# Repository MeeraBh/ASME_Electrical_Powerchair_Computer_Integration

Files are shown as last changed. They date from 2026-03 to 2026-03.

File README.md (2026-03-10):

# ASME Electrical Powerchair Computer Integration
This is repo contains the schematic, pcb, and gerber files from Kicad for a custom ortholinear split keyboard PCB as well as all files needed to order the pcb on JLCPCB.

This project was made for ASME - Product Development and will be shown at Engineering Open House.  

It is intended to be used for a powerchair in which the PCB contains the peripherals for the computer minus the monitor itself in which the mainboard of the computer is connected to the powerchair.  These peripherals are the keyboard itself, 2 OLED screens (Nice!Views), and 2 joysticks.  There are also a total of 3 microcontrollers (Nice!Nanos) that can connect to each other through bluetooth and communicate.  The keyboard can also be used as split design or merged together as a full keyboard due to the connections in the center.

# Keyboard
PCB
Screenshot 2026-03-09 at 12 35 01 AM
3D View Front
Screenshot 2026-03-09 at 12 34 24 AM
3D View Back
Screenshot 2026-03-09 at 12 36 32 AM
Schematic

Screenshot 2026-03-09 at 12 34 24 AM (2)

Gerber, BOM, and CTL (.pos) files in repo that are compatible with JLCPCB printing.

Details on full project: https://erinpc.vercel.app

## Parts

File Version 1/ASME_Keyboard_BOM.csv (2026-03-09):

Id | Designator | Footprint | Quantity | Designation | Supplier and ref
1 | SW28,SW36,SW40,SW15,SW35,SW26,SW31,SW17,SW24,SW18,SW38,SW1,SW21,SW16,SW5,SW33,SW22,SW41,SW34,SW4,SW32,SW12,SW42,SW14,SW23,SW37,SW30,SW3,SW9,SW10,SW7,SW27,SW20,SW6,SW19,SW25,SW11,SW13,SW2,SW8,SW29,SW39 | Kailh_socket_MX | 42 | SW_Push
2 | J16,J17,J6,J13,J15,J14 | MF_Connectors-POGO_PIN_70-9150 | 6 | Conn_01x01_Socket
3 | J1,J11,J10,J12,J9,J8 | MF_Connectors-POGO_PIN_70-9150 | 6 | Conn_01x01_Pin
4 | J22,J7,J20,J21,J19,J18 | PinHeader_1x05_P2.54mm_Vertical | 6 | Conn_01x05_Pin
5 | U1,U2,U3 | nice_nano | 3 | nice_nano
6 | J4,J2 | nice_view | 2 | Conn_01x05_Pin
7 | J3,J5 | Joycon_edited_5pin | 2 | Conn_01x05_Pin
8 | JP1 | SolderJumper-2_P1.3mm_Open_Pad1.0x1.5mm | 1 | Jumper_2_Bridged
9 | D11,D32,D40,D28,D5,D38,D25,D12,D8,D37,D29,D9,D21,D6,D14,D7,D42,D39,D23,D19,D15,D13,D36,D17,D3,D10,D30,D22,D27,D31,D35,D4,D18,D26,D16,D20,D1,D24,D34,D41,D33,D2 | D_1206_3216Metric | 42 | D

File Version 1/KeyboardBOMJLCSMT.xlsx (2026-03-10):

Comment | Designator | Footprint | JLCPCB Part #（optional）
SW_Push | SW28,SW36,SW40,SW15,SW35,SW26,SW31,SW17,SW24,SW18,SW38,SW1,SW21,SW16,SW5,SW33,SW22,SW41,SW34,SW4,SW32,SW12,SW42,SW14,SW23,SW37,SW30,SW3,SW9,SW10,SW7,SW27,SW20,SW6,SW19,SW25,SW11,SW13,SW2,SW8,SW29,SW39 | Kailh_socket_MX | CPG135001S30
Conn_01x01_Socket | J16,J17,J6,J13,J15,J14 | MF_Connectors-POGO_PIN_70-9150
Conn_01x01_Pin | J1,J11,J10,J12,J9,J8 | MF_Connectors-POGO_PIN_70-9150
Conn_01x05_Pin | J22,J7,J20,J21,J19,J18 | PinHeader_1x05_P2.54mm_Vertical
nice_nano | U1,U2,U3 | nice_nano
Conn_01x05_Pin | J4,J2 | nice_view
Conn_01x05_Pin | J3,J5 | Joycon_edited_5pin | Molex 503480-0500
D | D11,D32,D40,D28,D5,D38,D25,D12,D8,D37,D29,D9,D21,D6,D14,D7,D42,D39,D23,D19,D15,D13,D36,D17,D3,D10,D30,D22,D27,D31,D35,D4,D18,D26,D16,D20,D1,D24,D34,D41,D33,D2 | D_1206_3216Metric | 1N4148W

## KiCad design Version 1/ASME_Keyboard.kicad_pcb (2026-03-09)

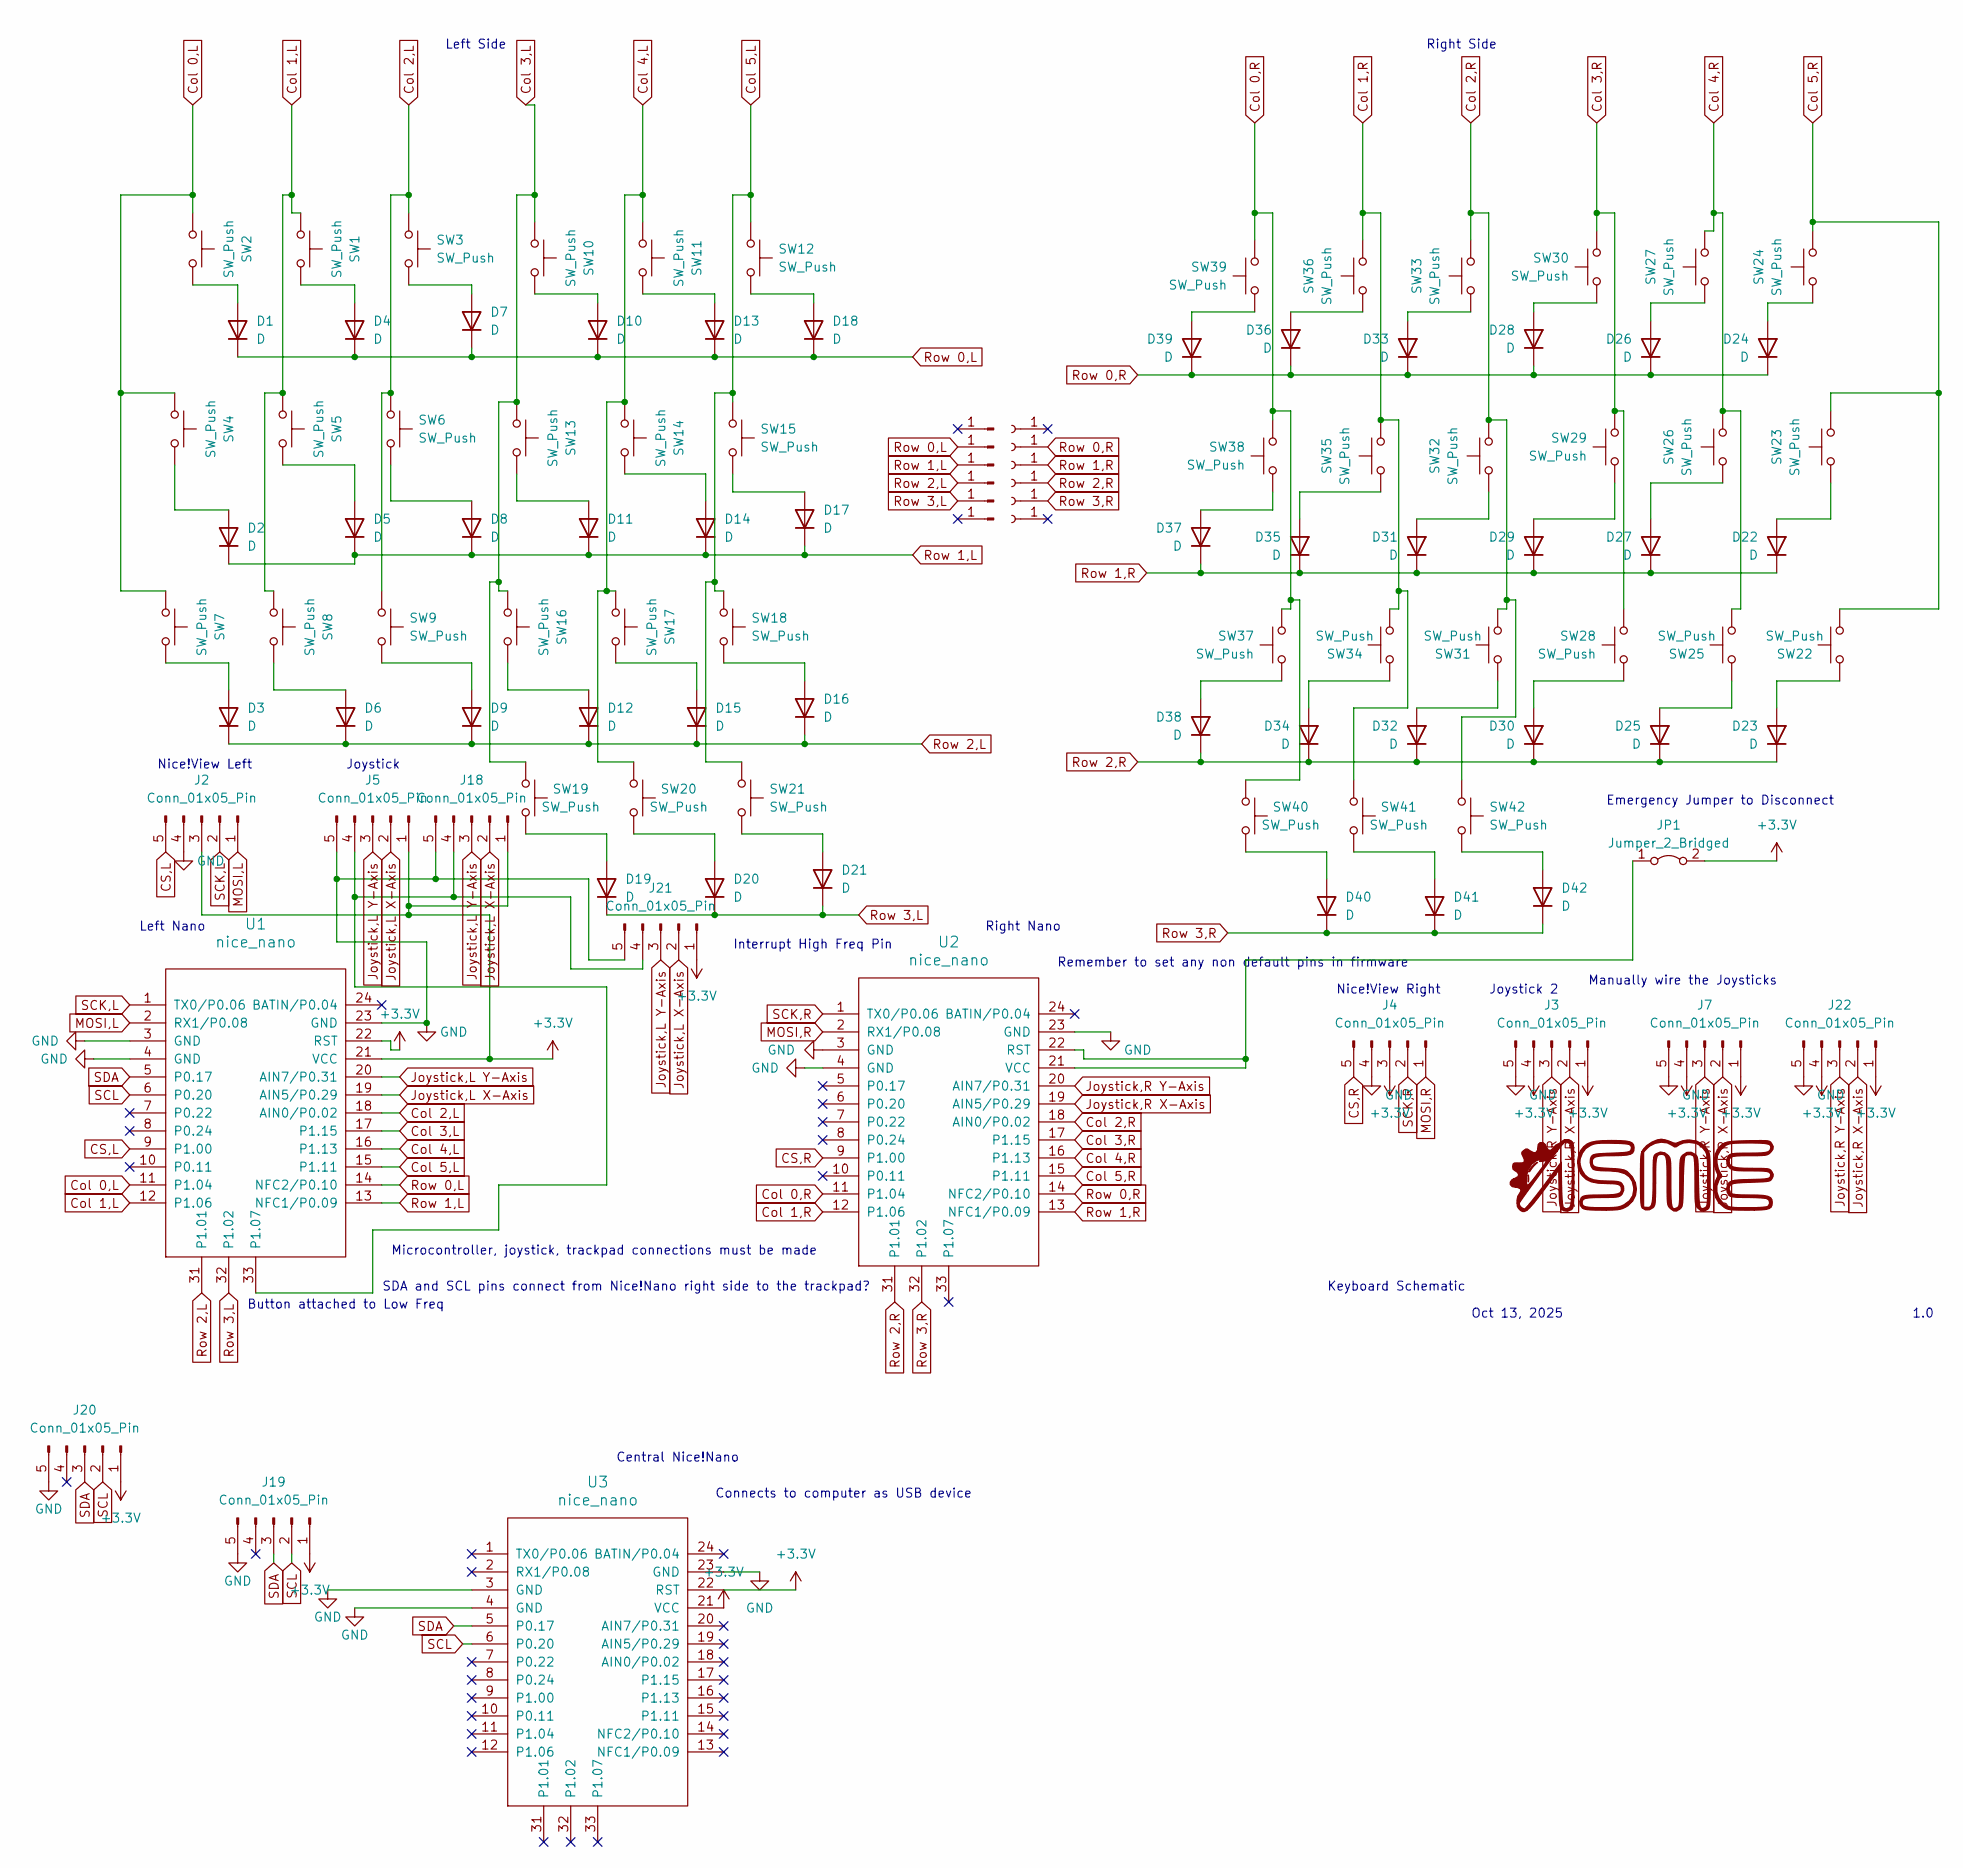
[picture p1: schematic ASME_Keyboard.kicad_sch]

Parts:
D1, D2, D3, D4, D5, D6, D7, D8, D9, D10, D11, D12, D13, D14, D15, D16, D17, D18, D19, D20, D21, D22, D23, D24, D25, D26, D27, D28, D29, D30, D31, D32, D33, D34, D35, D36, D37, D38, D39, D40, D41, D42: D; D_1206_3216Metric
J1, J8, J9, J10, J11, J12: Conn_01x01_Pin; MF_Connectors-POGO_PIN_70-9150
J2, J4: Conn_01x05_Pin; nice_view
J3, J5: Conn_01x05_Pin; Joycon_edited_5pin
J6, J13, J14, J15, J16, J17: Conn_01x01_Socket; MF_Connectors-POGO_PIN_70-9150
J7, J18, J19, J20, J21, J22: Conn_01x05_Pin; PinHeader_1x05_P2.54mm_Vertical
JP1: Jumper_2_Bridged; SolderJumper-2_P1.3mm_Open_Pad1.0x1.5mm
SW1, SW2, SW3, SW4, SW5, SW6, SW7, SW8, SW9, SW10, SW11, SW12, SW13, SW14, SW15, SW16, SW17, SW18, SW19, SW20, SW21, SW22, SW23, SW24, SW25, SW26, SW27, SW28, SW29, SW30, SW31, SW32, SW33, SW34, SW35, SW36, SW37, SW38, SW39, SW40, SW41, SW42: SW_Push; Kailh_socket_MX
U1, U2, U3: nice_nano

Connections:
+3.3V: J2.3, J3.1, J3.4, J4.3, J5.1, J7.1, J7.4, J18.1, J19.1, J20.1, J21.1, J22.1, J22.4, JP1.2 (B), U1.21 (VCC), U1.22 (RST), U3.21 (VCC), U3.22 (RST)
CS,L: J2.5, U1.9 (P1.00)
CS,R: J4.5, U2.9 (P1.00)
Col 0,L: SW2.1, SW4.1, SW7.1, U1.11 (P1.04)
Col 0,R: SW37.1, SW38.1, SW39.1, SW40.1, U2.11 (P1.04)
Col 1,L: SW1.1, SW5.1, SW8.1, U1.12 (P1.06)
Col 1,R: SW34.1, SW35.1, SW36.1, SW41.1, U2.12 (P1.06)
Col 2,L: SW3.1, SW6.1, SW9.1, U1.18 (AIN0/P0.02)
Col 2,R: SW31.1, SW32.1, SW33.1, SW42.1, U2.18 (AIN0/P0.02)
Col 3,L: SW10.1, SW13.1, SW16.1, SW19.1, U1.17 (P1.15)
Col 3,R: SW28.1, SW29.1, SW30.1, U2.17 (P1.15)
Col 4,L: SW11.1, SW14.1, SW17.1, SW20.1, U1.16 (P1.13)
Col 4,R: SW25.1, SW26.1, SW27.1, U2.16 (P1.13)
Col 5,L: SW12.1, SW15.1, SW18.1, SW21.1, U1.15 (P1.11)
Col 5,R: SW22.1, SW23.1, SW24.1, U2.15 (P1.11)
GND: J2.4, J3.5, J4.4, J5.5, J7.5, J18.5, J19.5, J20.5, J21.5, J22.5, U1.3 (GND), U1.4 (GND), U1.23 (GND), U2.3 (GND), U2.4 (GND), U2.23 (GND), U3.3 (GND), U3.4 (GND), U3.23 (GND)
Joystick,L X-Axis: J5.2, J18.2, J21.2, U1.19 (AIN5/P0.29)
Joystick,L Y-Axis: J5.3, J18.3, J21.3, U1.20 (AIN7/P0.31)
Joystick,R X-Axis: J3.2, J7.2, J22.2, U2.19 (AIN5/P0.29)
Joystick,R Y-Axis: J3.3, J7.3, J22.3, U2.20 (AIN7/P0.31)
MOSI,L: J2.1, U1.2 (RX1/P0.08)
MOSI,R: J4.1, U2.2 (RX1/P0.08)
unnamed: D1.2 (A), SW2.2
unnamed: D2.2 (A), SW4.2
unnamed: D3.2 (A), SW7.2
unnamed: D4.2 (A), SW1.2
unnamed: D5.2 (A), SW5.2
unnamed: D6.2 (A), SW8.2
unnamed: D7.2 (A), SW3.2
unnamed: D8.2 (A), SW6.2
unnamed: D9.2 (A), SW9.2
unnamed: D10.2 (A), SW10.2
unnamed: D11.2 (A), SW13.2
unnamed: D12.2 (A), SW16.2
unnamed: D13.2 (A), SW11.2
unnamed: D14.2 (A), SW14.2
unnamed: D15.2 (A), SW17.2
unnamed: D16.2 (A), SW18.2
unnamed: D17.2 (A), SW15.2
unnamed: D18.2 (A), SW12.2
unnamed: D19.2 (A), SW19.2
unnamed: D20.2 (A), SW20.2
unnamed: D21.2 (A), SW21.2
unnamed: D22.2 (A), SW23.2
unnamed: D23.2 (A), SW22.2
unnamed: D24.2 (A), SW24.2
unnamed: D25.2 (A), SW25.2
unnamed: D26.2 (A), SW27.2
unnamed: D27.2 (A), SW26.2
unnamed: D28.2 (A), SW30.2
unnamed: D29.2 (A), SW29.2
unnamed: D30.2 (A), SW28.2
unnamed: D31.2 (A), SW32.2
unnamed: D32.2 (A), SW31.2
unnamed: D33.2 (A), SW33.2
unnamed: D34.2 (A), SW34.2
unnamed: D35.2 (A), SW35.2
unnamed: D36.2 (A), SW36.2
unnamed: D37.2 (A), SW38.2
unnamed: D38.2 (A), SW37.2
unnamed: D39.2 (A), SW39.2
unnamed: D40.2 (A), SW40.2
unnamed: D41.2 (A), SW41.2
unnamed: D42.2 (A), SW42.2
unnamed: J5.4, J18.4, J21.4, U1.33 (P1.07)
unnamed: JP1.1 (A), U2.21 (VCC), U2.22 (RST)
Row 0,L: D1.1 (K), D4.1 (K), D7.1 (K), D10.1 (K), D13.1 (K), D18.1 (K), J1.1, U1.14 (NFC2/P0.10)
Row 0,R: D24.1 (K), D26.1 (K), D28.1 (K), D33.1 (K), D36.1 (K), D39.1 (K), J13.1, U2.14 (NFC2/P0.10)
Row 1,L: D2.1 (K), D5.1 (K), D8.1 (K), D11.1 (K), D14.1 (K), D17.1 (K), J8.1, U1.13 (NFC1/P0.09)
Row 1,R: D22.1 (K), D27.1 (K), D29.1 (K), D31.1 (K), D35.1 (K), D37.1 (K), J14.1, U2.13 (NFC1/P0.09)
Row 2,L: D3.1 (K), D6.1 (K), D9.1 (K), D12.1 (K), D15.1 (K), D16.1 (K), J9.1, U1.31 (P1.01)
Row 2,R: D23.1 (K), D25.1 (K), D30.1 (K), D32.1 (K), D34.1 (K), D38.1 (K), J15.1, U2.31 (P1.01)
Row 3,L: D19.1 (K), D20.1 (K), D21.1 (K), J10.1, U1.32 (P1.02)
Row 3,R: D40.1 (K), D41.1 (K), D42.1 (K), J16.1, U2.32 (P1.02)
SCK,L: J2.2, U1.1 (TX0/P0.06)
SCK,R: J4.2, U2.1 (TX0/P0.06)
SCL: J19.2, J20.2, U1.6 (P0.20), U3.6 (P0.20)
SDA: J19.3, J20.3, U1.5 (P0.17), U3.5 (P0.17)

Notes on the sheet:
Manually wire the Joysticks
Button attached to Low Freq
Interrupt High Freq Pin
Keyboard Schematic
Joystick 2
Oct 13, 2025
Remember to set any non default pins in firmware
Nice!View Right
SDA and SCL pins connect from Nice!Nano right side to the trackpad?
Emergency Jumper to Disconnect
Connects to computer as USB device
Microcontroller, joystick, trackpad connections must be made
Right Nano
Joystick
Left Side
Central Nice!Nano
Left Nano
1.0
Right Side
Nice!View Left

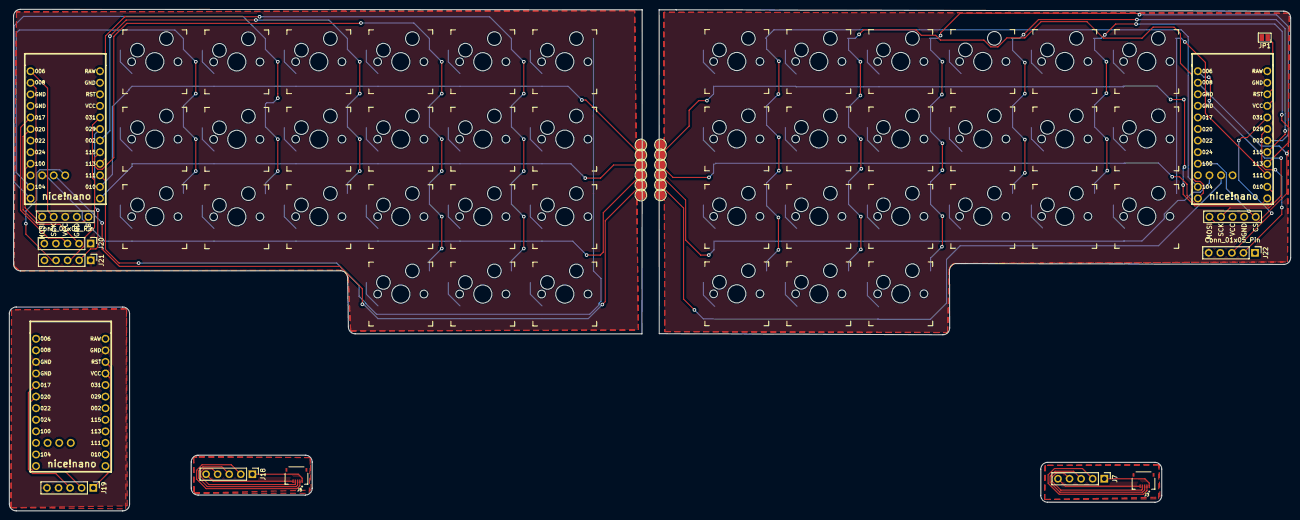
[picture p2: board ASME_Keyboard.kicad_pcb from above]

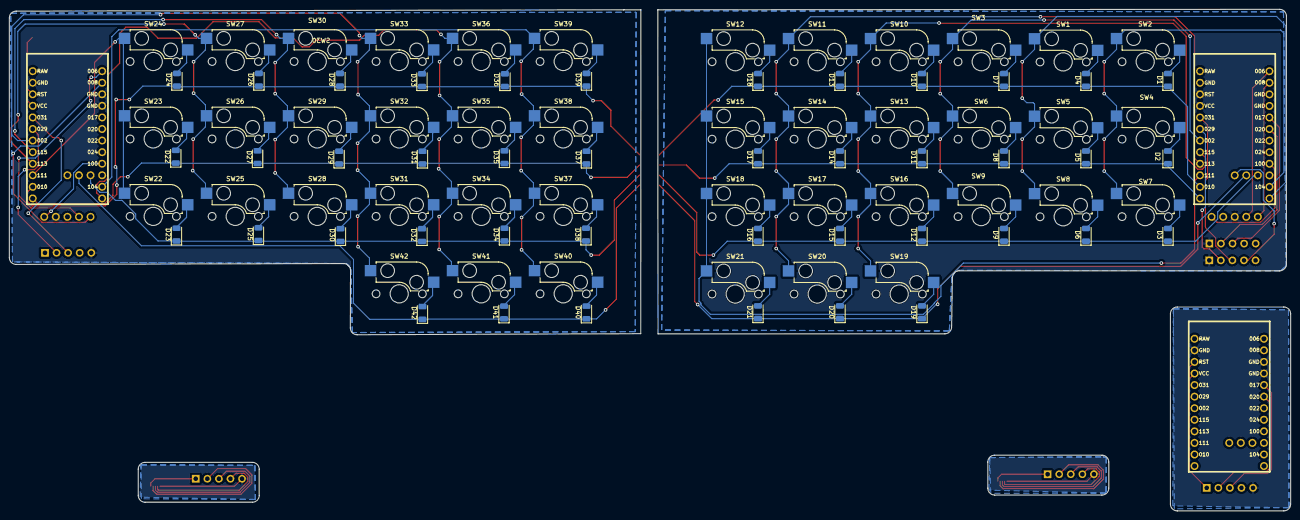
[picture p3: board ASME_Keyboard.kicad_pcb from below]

Board: 2 copper layers, 281.3 x 110.1 mm, 110 parts (42 on the bottom side), 78 nets.

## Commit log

2025-10-14 Original push of files for Keyboard
    [ASME_Keyboard.kicad_pcb, ASME_Keyboard.kicad_sch]
2026-03-09 All PCB files
    Need to change position file to not have negative numbers for rotations, match formatting to sent to manufacturing
    [ASME_Keyboard.kicad_pcb, ASME_Keyboard.kicad_sch, ASME_Keyboard_BOM.csv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]
2026-03-10 Gerbers and JLCPCB Compatible Files
    [KeyboardBOMJLCSMT.xlsx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]
2026-09-06 Version 1 Folder
    [ASME_Keyboard.kicad_pcb, ASME_Keyboard.kicad_sch, ASME_Keyboard_BOM.csv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]
